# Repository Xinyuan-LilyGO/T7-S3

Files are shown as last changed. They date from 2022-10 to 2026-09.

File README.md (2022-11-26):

<h1 align = "center">🌟LILYGO T7-S3🌟</h1>

## **English | [中文](./README_CN.MD)**

## Quick start

**USE PlatformIO**

1. Install[VSCODE](https://code.visualstudio.com/)and[Python](https://www.python.org/)
2. Search for the PlatformIO plug-in in the VSCODE extension and install it.
3. After the installation is complete and the reload is completed, there will be a small house icon in the lower left corner. Click to display the Platformio IDE home page
4. Go to file - > Open folder - > Select the T7-S3 folder and click the (√) symbol in the lower left corner to compile (→) for upload.

**USE Arduino IDE**

1. Install the current upstream Arduino IDE at the 1.8 level or later. The current version is at the [Arduino website](http://www.arduino.cc/en/main/software).
2. Start Arduino and open Preferences window. In additional board manager add url: https://raw.githubusercontent.com/espressif/arduino-esp32/gh-pages/package_esp32_index.json .separating them with commas.
3. Select Tools -> Board -> ESP32S3 Dev Module

**USE Micropython**

1. [Download and upload the firmware](https://github.com/Xinyuan-LilyGO/T7-S3/issues/1)

## Specification

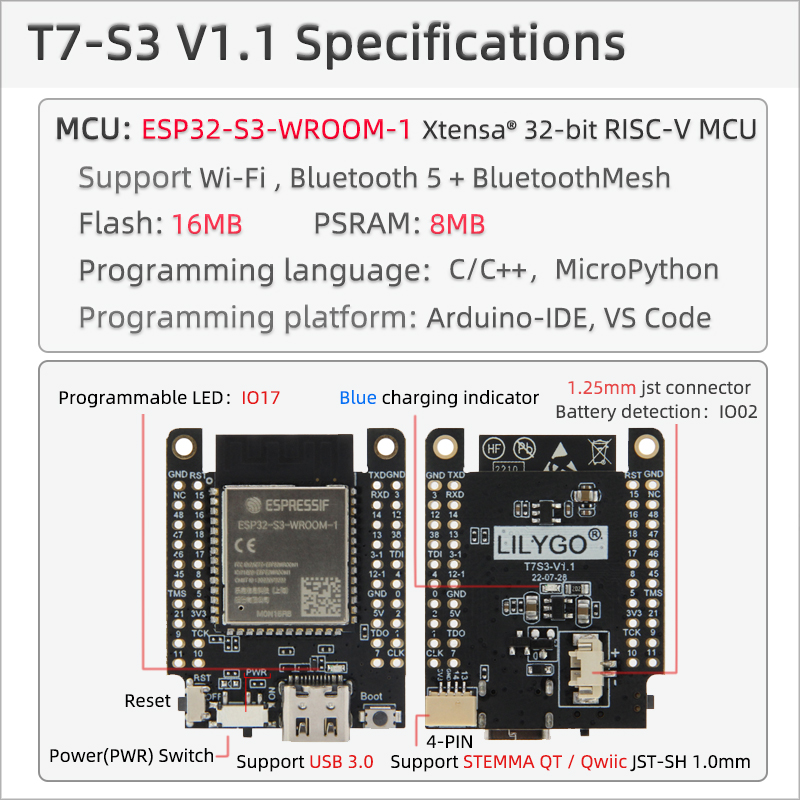
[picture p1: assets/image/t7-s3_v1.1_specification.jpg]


## Pinout

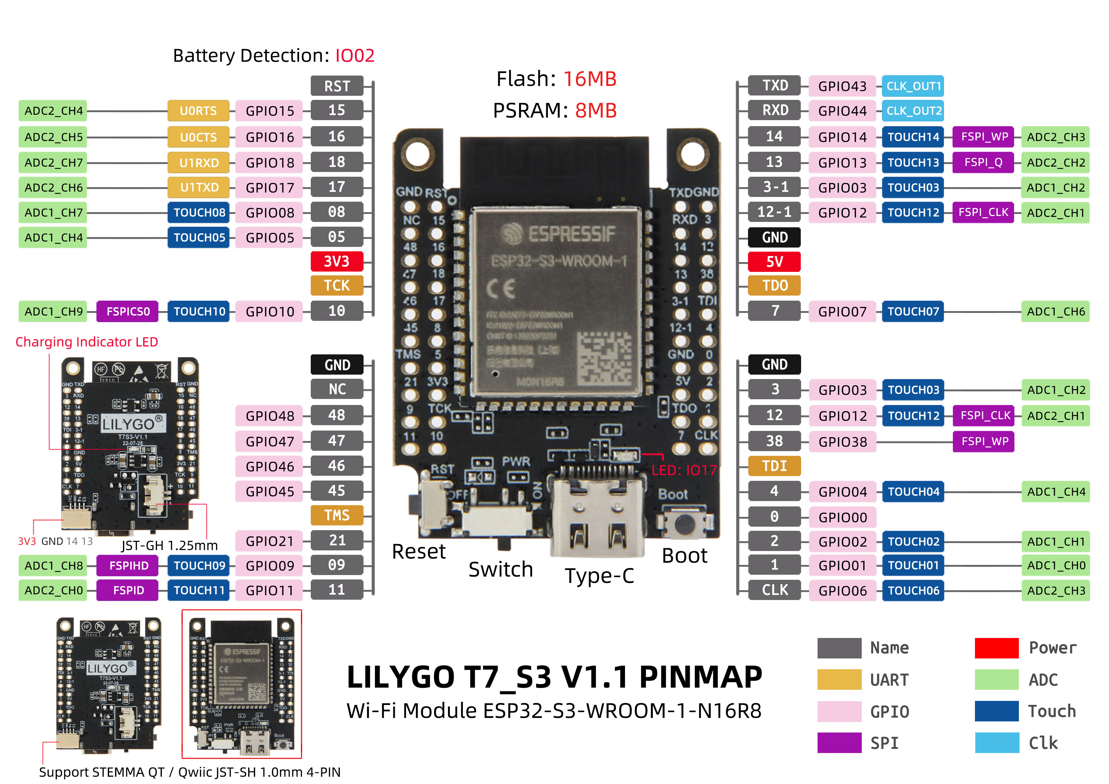
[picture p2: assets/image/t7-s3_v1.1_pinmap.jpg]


## Sleep Test

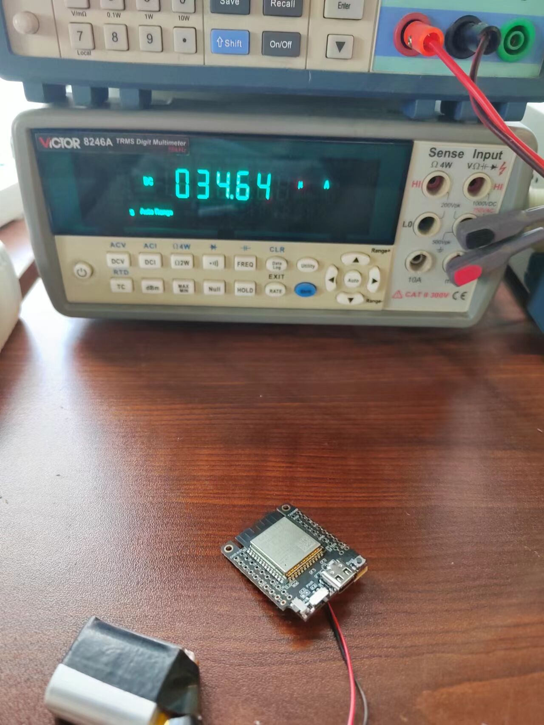
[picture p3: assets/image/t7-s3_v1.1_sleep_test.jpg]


## Product 📷

| Product | Product  Link |
| :-----: | :---: |
|  T7-S3  | [AliExpress](https://www.aliexpress.us/item/3256804591247074.html) |

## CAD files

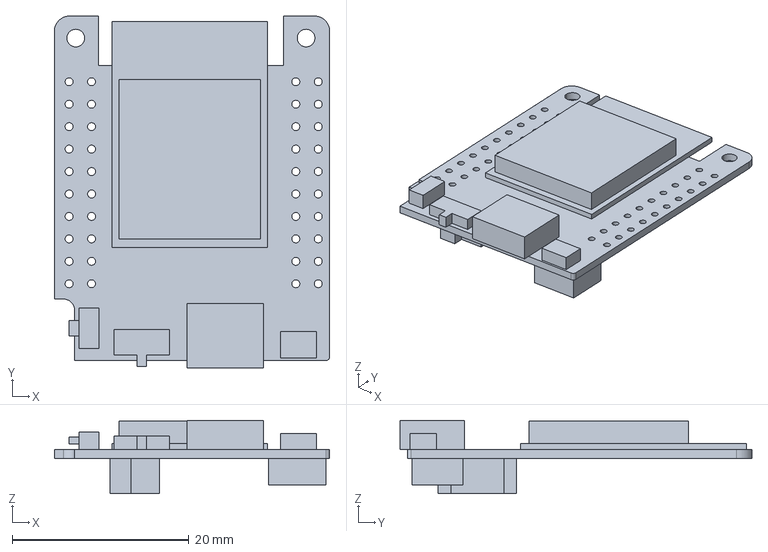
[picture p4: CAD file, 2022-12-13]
3D_File/T7S3-V1.2.stp
31.2 x 39.8 x 8.30 mm

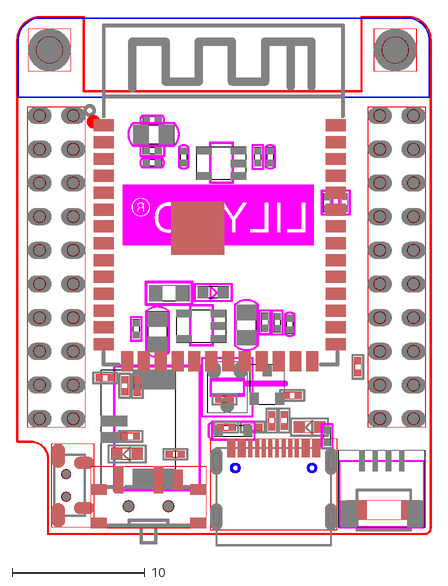
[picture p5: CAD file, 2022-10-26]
T7S3-V1.1.dxf
31.3 x 40.0

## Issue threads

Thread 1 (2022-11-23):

Esptool Instructions?

jouellnyc, 2022-11-23:
Hello.

I've just gotten the "LILYGO T7-S3 ESP32-S3 board with 16MB flash, 8MB PSRAM"

Are there steps for using esptool to flash?

I've tried:

```
esptool.py --chip ESP32S3  --port /dev/ttyACM0 write_flash -z 0x0000 ~/esp32/firmware/esp32spiram-20221111-unstable-v1.19.1-660-gc8913fdbf.bin  --force
esptool.py v4.3
Serial port /dev/ttyACM0
Connecting...
Chip is ESP32-S3 (revision v0.1)
Features: WiFi, BLE
Crystal is 40MHz
MAC: f4:12:fa:e1:d7:90
Uploading stub...
Running stub...
Stub running...
Configuring flash size...
Flash will be erased from 0x00000000 to 0x00173fff...
Compressed 1521472 bytes to 985597...
Wrote 1521472 bytes (985597 compressed) at 0x00000000 in 10.7 seconds (effective 1134.4 kbit/s)...
Hash of data verified.

Leaving...
Hard resetting via RTS pin...

```

On boot gtmkterm will show:

```
Build:Mar 27 2021
rst:0x7 (TG0WDT_SYS_RST),boot:0x8 (SPI_FAST_FLASH_BOOT)
Saved PC:0x40043ac8
Invalid chip id. Expected 9 read 0. Bootloader for wrong chip?
ets_main.c 329
ESP-ROM:esp32s3-20210327

```

Most options give errors regarding the chip id, that's why I tried --force:

```
esptool.py --chip ESP32S3   --port /dev/ttyACM0 write_flash -z 0x0000 ~/esp32/firmware/esp32spiram-20221111-unstable-v1.19.1-660-gc8913fdbf.bin
esptool.py v4.3
Serial port /dev/ttyACM0
Connecting...
Chip is ESP32-S3 (revision v0.1)
Features: WiFi, BLE
Crystal is 40MHz
MAC: f4:12:fa:e1:d7:90
Uploading stub...
Running stub...
Stub running...
Configuring flash size...
Unexpected chip id in image. Expected 9 but value was 0. Is this image for a different chip model?

A fatal error occurred: /home/john/esp32/firmware/esp32spiram-20221111-unstable-v1.19.1-660-gc8913fdbf.bin is not an ESP32-S3 image. Use --force to flash anyway.

```

lbuque, 2022-11-25:
Where is [this firmware](esp32spiram-20221111-unstable-v1.19.1-660-gc8913fdbf.bin) obtained from?

jouellnyc, 2022-11-25:
Hello. Thanks for the reply. I've tried the firmware here: https://micropython.org/resources/firmware/GENERIC_S3_SPIRAM-20220618-v1.19.1.bin

lbuque, 2022-11-26:
There is currently no micropython firmware for the T7-S3.

you can try this [firmware](https://github.com/Xinyuan-LilyGO/lilygo-micropython/suites/8922903601/artifacts/409089943).

jouellnyc, 2022-11-26:
Thank you!

I have tried:

```
esptool.py --chip ESP32S3  --port /dev/ttyACM0 write_flash -z 0x0000 LilyGo-MicroPython_esp32s3_LILYGO_T-DisplayS3_MPY-d7919ea71_IDF-1b16ef6cfc_B20221024_a07409ec59.bin

esptool.py v4.3
Serial port /dev/ttyACM0
Connecting...
Chip is ESP32-S3 (revision v0.1)
Features: WiFi, BLE
Crystal is 40MHz
MAC: f4:12:fa:e1:d7:90
Uploading stub...
Running stub...
Stub running...
Configuring flash size...
Flash will be erased from 0x00000000 to 0x0017cfff...
Compressed 1557328 bytes to 991536...
Wrote 1557328 bytes (991536 compressed) at 0x00000000 in 10.7 seconds (effective 1162.2 kbit/s)...
Hash of data verified.

Leaving...
Hard resetting via RTS pin...

```
It works now and I use it with Thonny IDE.

Thank you @lbuque !!!

lbuque, 2022-11-26:
This is the micropython [firmware](https://github.com/Xinyuan-LilyGO/lilygo-micropython/suites/9514697728/artifacts/451759541) for T7-S3.

This is the board micropython configuration code of T7-S3.

https://github.com/Xinyuan-LilyGO/lilygo-micropython/tree/master/target/esp32s3/boards/LILYGO_T7-S3

For subsequent micropython issues related to this board, please move to https://github.com/Xinyuan-LilyGO/lilygo-micropython/issues.

This issue will be closed.

jouellnyc, 2022-11-26:
Thanks again for the information and response.

Closed 2022-11-26.

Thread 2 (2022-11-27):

Missing 5.1k resistors on USB connector in schematic

nikthefix, 2022-11-27:
CC1/2 on the USB C connector are not pulled to GND via 5.1k resistors as would be expected according to spec. Could be an issue with upstream type C hosts.

LilyGO, 2022-11-30:
Hello. The schematics have been updated

Closed 2022-11-30.

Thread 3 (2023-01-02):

Wrong serial port in examples > test, battery readouts not printed to the console

ddekanski, 2023-01-02:
In the code of the main example - test.ino - battery measurements are improperly printed out to `Serial1` instead of `Serial`. The following lines:
```
        Serial1.printf("%.2fV", Voltage / 1000.0); // Print Voltage (in V)
        Serial1.println();
```

should read:

```
        Serial.printf("%.2fV", Voltage / 1000.0); // Print Voltage (in V)
        Serial.println();
```

LilyGO, 2023-01-03:
Thank you for your feedback. Modified

Closed 2023-01-03.

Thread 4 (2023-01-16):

Qwiic/Stemma QT connector, GND and 3.3 V pins are swapped

yltsa, 2023-01-16:
Hi, In my T7-S3 module the GND and 3.3V pins are swapped in the Qwiic/Stemma QT connector. It took a long time to understand what was wrong. The sensor got really hot as did one part in the T7-S3 module.

T-Display-S3 works OK.

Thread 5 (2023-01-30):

Touch Pins

disruptivepatternmaterial, 2023-01-30:
Has anyone been able to get the touch pins to work? I have tried many ways including just reading all of them and touching them one at a time. None of them register. On my other esp32s3 modules they "just work." So I think something is broken with this board. I'd love to be wrong and find out the secret to using them here.

maxdd, 2023-06-10:
IO2, which is TOUCH2, is used to sense the battery so that cannot be used.
I'm not an expert with TOUCH but if you say you should touch them individually and expect them to register and they dont, maybe it's a PU/PD issue?

jalmince, 2023-06-13:
for me it works !

touch GPIO04 and touchRead(4) increases about 10 fold

Touch: 27771
Touch: 28479
Touch: 29602
Touch: 216505  (touched)
Touch: 321552  (touched)
Touch: 360484  (touched)
Touch: 320490  (touched)
Touch: 23546
Touch: 23466
Touch: 23474
```
#include <Arduino.h>
#define BAT_ADC        2
#define LED_PIN        17

void setup() {
  Serial.begin(115200);
  delay(1000);
  Serial.println("ESP32 Touch Test");
}

void loop() {
  Serial.print("Touch: ");
  Serial.println(touchRead(4));  // get touch value on GPIO 4
  delay(1000);
}
```

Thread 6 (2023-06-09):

Battery status

dima-fedotovs, 2023-06-09:
How to read battery status/voltage? I'm using ESPHome config:

```
sensor:
    - platform: adc
      id: battery_level
      pin: 2
```

And this sensor always shows the same value. Is it possible to measure the voltage on pin 2?

maxdd, 2023-06-10:
Not sure about ESPHome but with my c code on pin 2 i can read the battery voltage

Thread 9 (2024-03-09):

power on 3.3v pin when power switch off

dskogman, 2024-03-09:
I found that there is 0.4v on the 3.3v pin when the power switch is turned off and a battery and/or USB is connected. This is causing the battery to drain. Any way to correct this?

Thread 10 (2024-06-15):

Arduino IDE Program upload does not start automatically

StuartsProjects, 2024-06-15:
Just got one of the LilyGo T7 S3 V1.2, and congratulations, the deep sleep current is 34uA !

I have a couple of ESP32S3 Dev kit boards too and when upload a program to them, the upload starts automatically, no need for the BOOT and RESET buttons, the program then runs automatically.

On the LilyGo T7 S3 I need to hold down BOOT and press RESET to go into download mode. I then need to press RESET to run the program. The Arduino IDE (1.8.19) settings are the exact same as those used for the ESP32S3 Dev kit board.

Checking the schematics, the connections from USB to ESP32S3 seem to be the same for both ESP32S3 boards, which maybe suggests the  LilyGo T7 S3 has a different bootloader ?

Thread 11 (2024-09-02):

Where to find I2C pins

hcl-83, 2024-09-02:
Hello,
i want to connect MPU-9250 sensor but dont see any of I2C pins on chart :

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

Can i use any of gpio 45-48 ??

cpocol, 2025-06-21:
Look for Wire_SCL and Wire_SCA (pins 22, 21)

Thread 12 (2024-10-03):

ADC Pins on GPIO4 and GPIO5

lost-hope, 2024-10-03:
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
I just saw that in the Pinout the GPIO 5 and GPIO4 share the Same ADC Channel.
Is this a mistake in the Pinout?

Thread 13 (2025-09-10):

Dimensions and pin spacing: how much space between pin columns

zef, 2025-09-10:
I am trying to design something to fit this footprint and I do not have a board physically.

The 3d model appears to have spacing between columns of pins that is .25mm larger than a standard .1" pitch.

The model shows 23.11mm between centers on the inside columns, and 28.19mm between centers on the outside columns.
To match .1" pitch, I would expect these to be 22.86 and 27.94, so each one is +.25mm from what I would expect.

Are the models correct? Does the board fit in a normal perfboard easily?

Thank you.

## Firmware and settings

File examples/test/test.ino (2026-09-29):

#define BAT_ADC        2
#define LED_PIN        17
#define BUTTON_PIN     0
#define uS_TO_S_FACTOR 1000000ULL  /* Conversion factor for micro seconds to seconds */
#define TIME_TO_SLEEP  20        /* Time ESP32 will go to sleep (in seconds) */

#include <WiFi.h>
#include <Arduino.h>
float Voltage = 0.0;
uint32_t        blinkMillis = 0;
RTC_DATA_ATTR int bootCount = 0;

bool readkey()
{

    if (digitalRead(BUTTON_PIN) == 0) {
        delay(100);
        //Wait for release
        while (digitalRead(BUTTON_PIN) == 0);
        return true;
    }
    return false;

}

void setup()
{
    Serial.begin(115200);
    delay(10);

    pinMode(LED_PIN, OUTPUT);
    digitalWrite(LED_PIN, HIGH);


    // Set WiFi to station mode and disconnect from an AP if it was previously connected
    WiFi.mode(WIFI_STA);
    WiFi.disconnect();
    delay(100);

    Serial.println("scan start");

    // WiFi.scanNetworks will return the number of networks found
    int n = WiFi.scanNetworks();
    Serial.println("scan done");
    if (n == 0) {
        Serial.println("no networks found");
    } else {
        Serial.print(n);
        Serial.println(" networks found");
        for (int i = 0; i < n; ++i) {
            // Print SSID and RSSI for each network found
            Serial.print(i + 1);
            Serial.print(": ");
            Serial.print(WiFi.SSID(i));
            Serial.print(" (");
            Serial.print(WiFi.RSSI(i));
            Serial.print(")");
            Serial.println((WiFi.encryptionType(i) == WIFI_AUTH_OPEN) ? " " : "*");
            delay(10);
        }
    }
    Serial.println("");

}

void loop()
{

    if (millis() - blinkMillis > 1000) {
        blinkMillis = millis();
        Voltage = (analogReadMilliVolts(BAT_ADC)) * 2;
        Serial.printf("%.2fV", Voltage / 1000.0); // Print Voltage (in V)
        Serial.println();
    }

    if (readkey()) {
        digitalWrite(LED_PIN, !digitalRead(LED_PIN));
        delay(200);
    }

}

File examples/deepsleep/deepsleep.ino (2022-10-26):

#define uS_TO_S_FACTOR 1000000ULL  /* Conversion factor for micro seconds to seconds */
#define TIME_TO_SLEEP  5        /* Time ESP32 will go to sleep (in seconds) */

RTC_DATA_ATTR int bootCount = 0;

/*
Method to print the reason by which ESP32
has been awaken from sleep
*/
void print_wakeup_reason()
{
    esp_sleep_wakeup_cause_t wakeup_reason;

    wakeup_reason = esp_sleep_get_wakeup_cause();

    switch (wakeup_reason) {
    case ESP_SLEEP_WAKEUP_EXT0 : Serial.println("Wakeup caused by external signal using RTC_IO"); break;
    case ESP_SLEEP_WAKEUP_EXT1 : Serial.println("Wakeup caused by external signal using RTC_CNTL"); break;
    case ESP_SLEEP_WAKEUP_TIMER : Serial.println("Wakeup caused by timer"); break;
    case ESP_SLEEP_WAKEUP_TOUCHPAD : Serial.println("Wakeup caused by touchpad"); break;
    case ESP_SLEEP_WAKEUP_ULP : Serial.println("Wakeup caused by ULP program"); break;
    default : Serial.printf("Wakeup was not caused by deep sleep: %d\n", wakeup_reason); break;
    }
}

void setup()
{
    Serial.begin(115200);
    delay(1000); //Take some time to open up the Serial Monitor

    //Increment boot number and print it every reboot
    ++bootCount;
    Serial.println("Boot number: " + String(bootCount));

    //Print the wakeup reason for ESP32
    print_wakeup_reason();

    /*
    First we configure the wake up source
    We set our ESP32 to wake up every 5 seconds
    */
    esp_sleep_enable_timer_wakeup(TIME_TO_SLEEP * uS_TO_S_FACTOR);
    Serial.println("Setup ESP32 to sleep for every " + String(TIME_TO_SLEEP) +
                   " Seconds");


    Serial.println("Going to sleep now");
    Serial.flush();
    esp_deep_sleep_start();
    Serial.println("This will never be printed");
}

void loop()
{
    //This is not going to be called
}

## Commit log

2022-10-26 test：Add Example
2022-12-13 3D file upload
    [T7S3-V1.2.stp]
